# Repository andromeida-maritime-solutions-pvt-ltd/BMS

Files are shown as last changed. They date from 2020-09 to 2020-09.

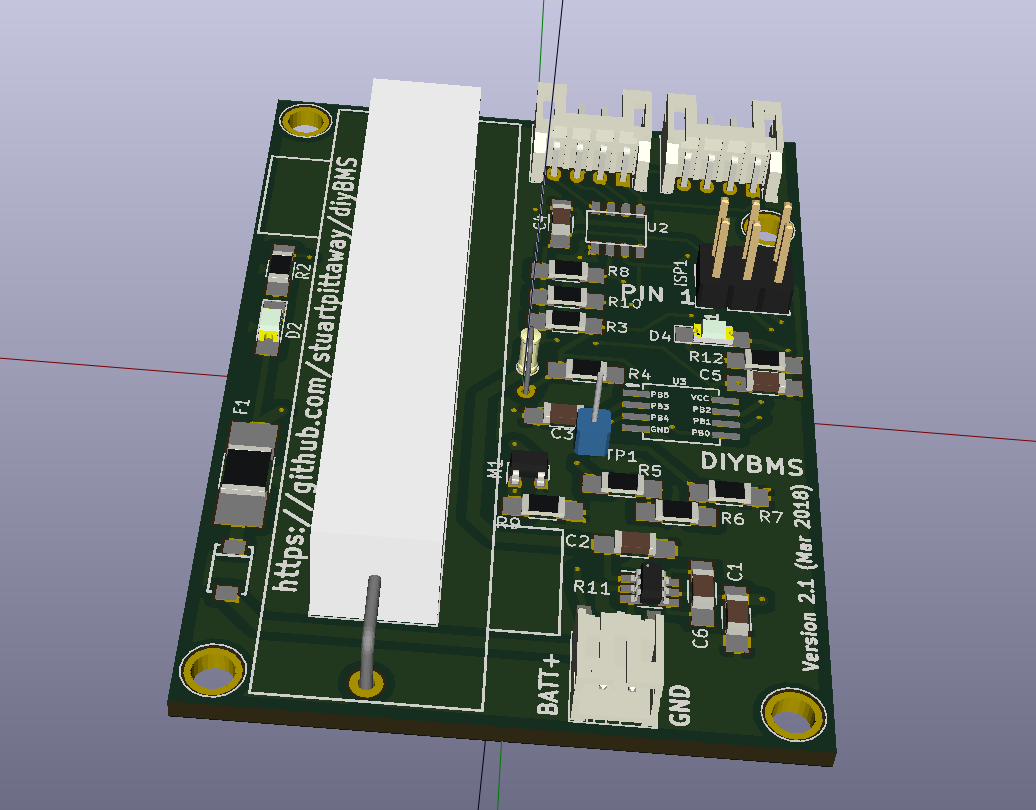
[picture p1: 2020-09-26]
BMS-Cell-Module-Circuit/BMS_Cell_Module2.png

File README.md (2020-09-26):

# diyBMS
Do it yourself battery management system to Lithium ion battery packs/cells

More discussion
https://community.openenergymonitor.org/t/diy-lithium-battery-balancer-and-monitoring-bms/5594/10

Some Youtube videos on the BMS building and testing can be found at
https://www.youtube.com/playlist?list=PLiYbY8lzAN-2qB9rR0Sc7Z7sUrsgYzsiV

# Problem

A DIY Powerwall is the DIY construction of a pack of battery cells to create an energy store which can be used via inverters to power electrical items in the home. Generally cells are salvaged/second hand, and typically use Lithium 18650 cells.

Lithium batteries need to be kept at the same voltage level across a parallel pack. This is done by balancing each cell in the pack to raise or lower its voltage to match the others.

Existing balancing solutions are available in the market place, but at a relatively high cost compared to the cost of the battery bank, so this project is to design a low-cost, simple featured BMS/balancer.

A large number of people have utilised the commercial BATRIUM BMS system in their powerwall devices.

# Parameters
**Current Situation:**
Assumption that second hand 18650 cells are made into “packs” containing tens or hundreds of cells in parallel.
Voltage of 18650 cell between 3.0V (empty) and 4.2V (full)
48V DC battery pack - running 14 packs/cells in series (aka 14S) this gives between 42V and 58.8V DC
Battery expected to output (1000W) so produce up to 25A current (depending on battery voltage)
Charger and inverter would be commercial products (not DIY) to comply with necessary approvals
BMS Design
Building upon my existing skill set and knowledge, and also building something that others can contribute to using regular standard libraries and off the shelf components.

* Design a hub and spoke arrangement, for a central controller and individual cell monitoring nodes on each pack (so 14 in my case)
* Use Arduino based libraries and tools (possible move to platform.io) **
* Use esp8266-12e as the controller - to take advantage of built in WIFI for monitoring/alerting and CPU/RAM performance
* Use AVR ATTINY85 for each node
* Ensure each cell voltage is isolated from other cells and that ground voltage is isolated
* Isolated communications between controller and node is needed
* Put everything on GITHUB
* Document it!

# Bill Of Materials

Typical bill of materials for each cell module, costs and part numbers provided from Farnell (UK) so other suppliers may be able to provide better costs or similar products.  The ADUM1250 unit is particularly expensive from Farnell and can be purchased for less than 1 USD if you shop around.  Excluding the ADUM1250 chip the component cost is around £5.50 GBP.

|	Quantity	|	Board Marking	|	Farnel (cost per single unit)	|	Make Model	|	Farnell URL	|
|	---	|	---	|	---	|	---	|	---	|
|	1	|	ATTINY85V-10SU SOIC-8	|	0.887	|	ATTINY85V-10SU	|	http://uk.farnell.com/atmel/attiny85v-10su/mcu-8bit-attiny-10mhz-soic-8/dp/1455166	|
|	1	|	REG710NA-3.3	|	1.20	|	REG710NA-3.3/250	|	http://uk.farnell.com/texas-instruments/reg710na-3-3-250/charge-pump-regulator-buck-boost/dp/1535743	|
|	1	|	ADUM1250ARZ SOIC-8	|	4.51	|	Analog Devices ADUM1250ARZ	|	http://uk.farnell.com/analog-devices/adum1250arz-rl7/digital-isolator-4-ch-1mbps-nsoic/dp/2758723	|
|	1	|	M1 SI2312BDS-T1-E3 MOSFET Transistor, N Channel, 3.9 A, 20 V, 0.025 ohm, 4.5 V, 850 mV	|	0.241	|	VISHAY SI2312BDS-T1-E3	|	http://uk.farnell.com/vishay/si2312bds-t1-e3/mosfet-n-ch-20v-3-9a-sot-23-3/dp/2396085	|
|	1	|	D1 SE30AFG-M3/6A Standard Recovery Diode, 400 V, 3 A, Single, 1.1 V, 1.5 µs, 40 A	|	0.306	|	VISHAY SE30AFG-M3/6A	|	http://uk.farnell.com/vishay/se30afg-m3-6a/rectifier-esd-400v-3a-do-221ac/dp/2313878	|
|	1	|	F1 MC36228 PPTC Resettable Fuse, 1.5A 8V	|	0.08	|	MultiComp MC36228	|	http://uk.farnell.com/multicomp/mc36228/fuse-ptc-reset-smd-8v-1-5a/dp/1861169	|
|	1	|	B57891M0103K000 Thermistor, NTC, 10 kohm, B57891M Series, 3950 K, Through Hole	|	0.571	|	EPCOS B57891M0103K000	|	http://uk.farnell.com/epcos/b57891m0103k000/thermistor-ntc-radial-leaded/dp/2285471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	|
|	1	|	1x GREEN LED 1206 SMT	|		|		|		|
|	1	|	1x BLUE LED 1206 SMT	|	0.12	|	King Bright KPL-3015QBC-D	|	http://uk.farnell.com/kingbright/kpl-3015qbc-d/led-blue-200mcd-465nm-smd/dp/2426226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	|
|	3	|	C3/C4/C5 0.1uF Cap 1210 SMT SMD Multilayer Ceramic Capacitor, 1210 [3225 Metric], 0.1 µF, 100 V, ± 10%, X7R, Y Series FF-CAP	|	0.15	|	KEMET C1210Y104K1RACTU	|	http://uk.farnell.com/kemet/c1210y104k1ractu/capacitor-1210-100nf-100v-x7r/dp/1520317	|
|	2	|	C1 2.2uF Cap 1210 SMT	|		|	X7R	|		|
|	2	|	C2 2.2uF Cap 1210 SMT	|		|	X7R	|		|
|	2	|	C6 0.22uF Cap 1210 SMT	|		|	X7R	|		|
|	1	|	R4 10K Resistor 1206 SMT	|		|		|		|
|	1	|	R5 47K Resistor 1206 SMT	|		|		|		|
|	1	|	R6 470K Resistor 1206 SMT	|		|		|		|
|	1	|	R7 680K Resistor 1206 SMT	|		|		|		|
|	1	|	R8 2K2 Resistor 1206 SMT	|		|		|		|
|	1	|	R3 20K Resistor 1206 SMT	|		|		|		|
|	1	|	R10 2K2 Resistor 1206 SMT	|		|		|		|
|	1	|	R11 510R Resistor 1206 SMT	|		|		|		|
|	1	|	R12 510R Resistor 1206 SMT	|		|		|		|
|	1	|	R11 2K2 Resistor 1206 SMT	|		|		|		|
|	1	|	R9 47K Resistor 1206 SMT	|		|		|		|
|	1	|	47R Resistor 1206 SMT	|		|		|		|
|	2	|	J2/J2 JST_PH_S4B-PH-K_04x2.00mm_Angled	|	0.10	|		S4B-PH-K-S (LF)(SN)	|	http://uk.farnell.com/jst-japan-solderless-terminals/s4b-ph-k-s-lf-sn/header-tht-right-angle-2mm-4way/dp/9492488	|
|	1	|	J1 	S2B-PH-K-S (LF)(SN)  	| 0.07		|	JST 	S2B-PH-K-S (LF)(SN)	|		|

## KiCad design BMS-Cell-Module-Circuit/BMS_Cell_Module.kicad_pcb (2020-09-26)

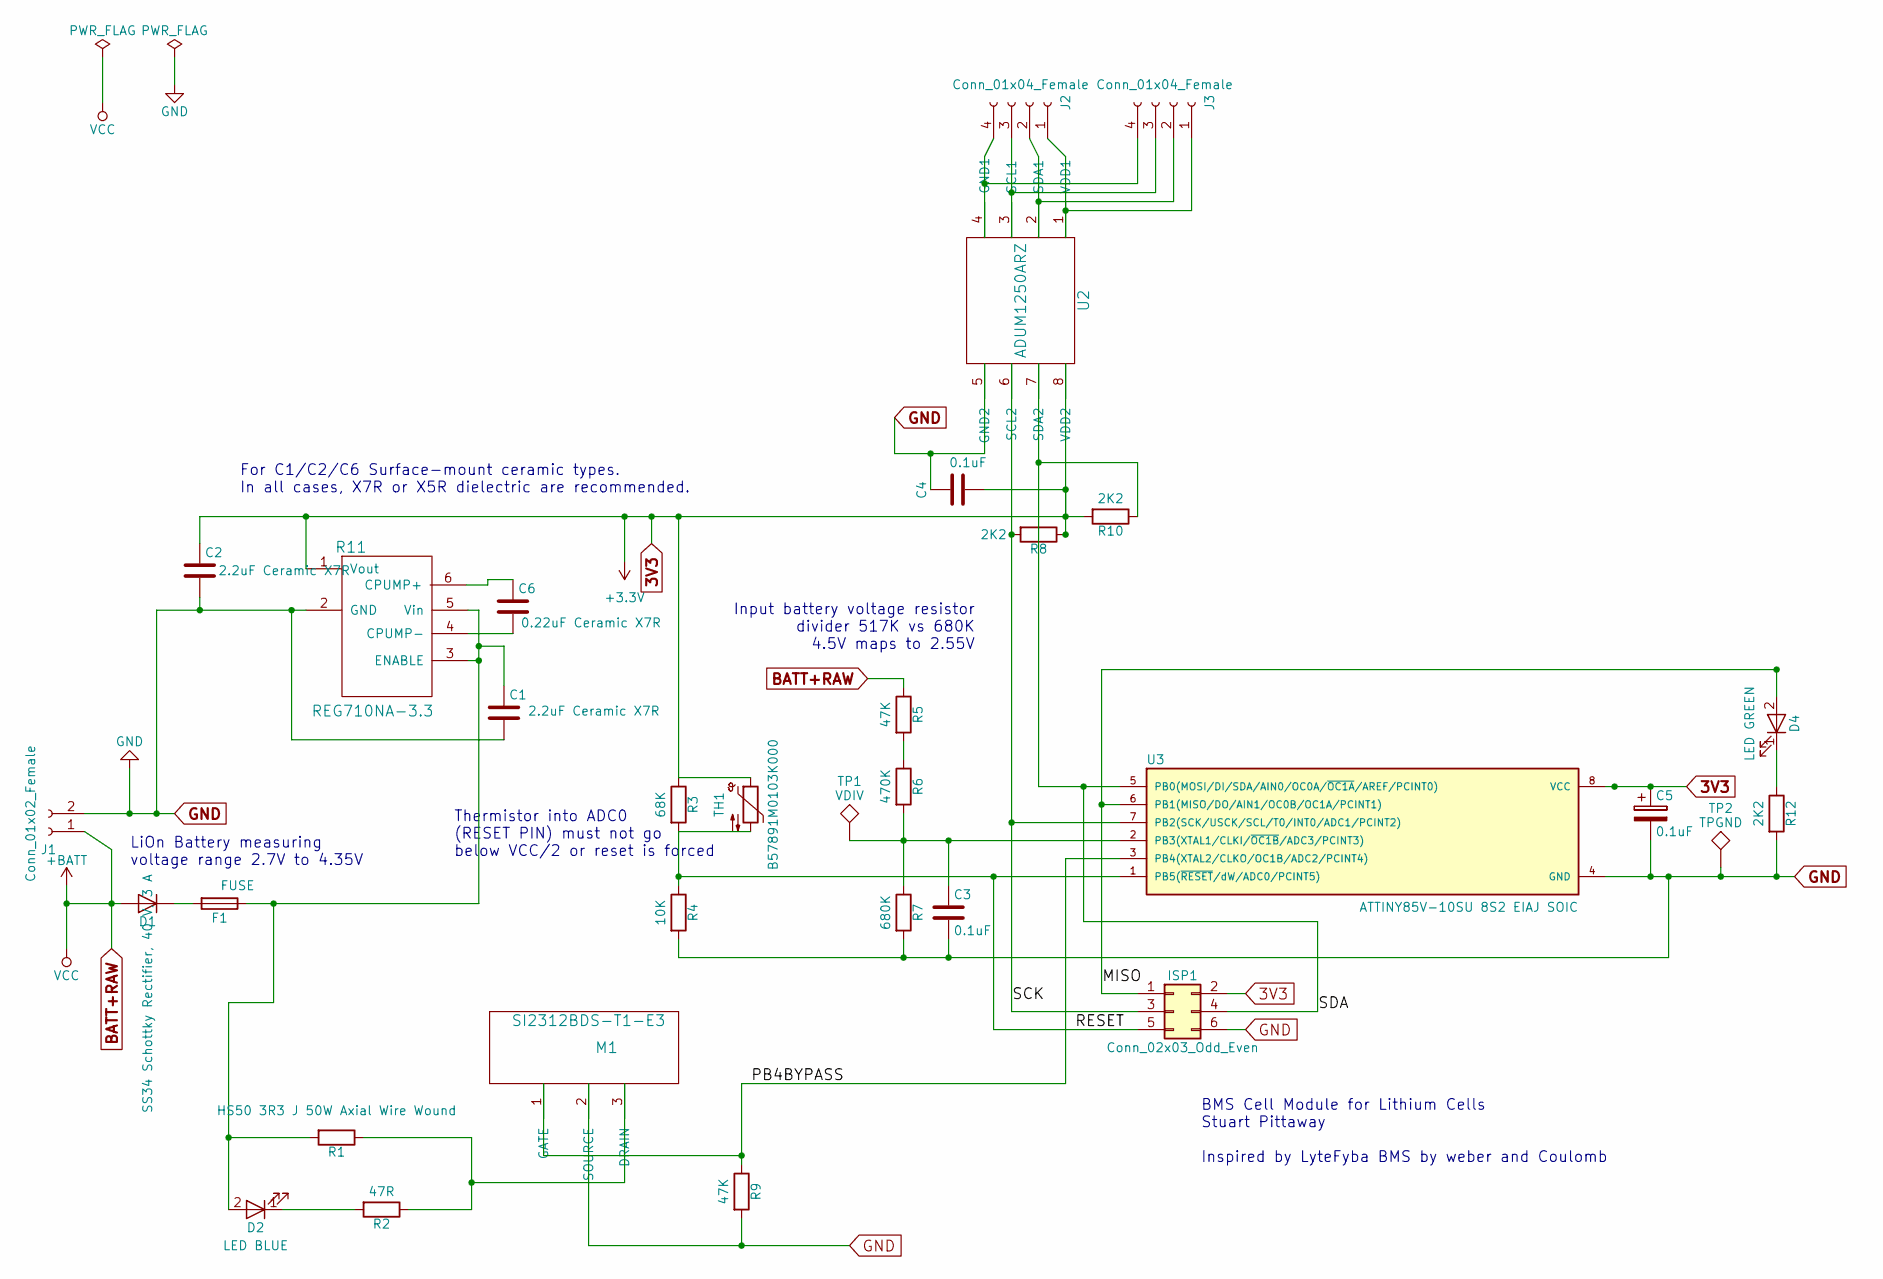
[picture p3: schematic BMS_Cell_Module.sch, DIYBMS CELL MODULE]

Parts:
C1, C2: 2.2uF Ceramic X7R; C_1206_HandSoldering
C3, C4, C5: 0.1uF; C_1206_HandSoldering
C6: 0.22uF Ceramic X7R; C_1206_HandSoldering
D1: SS34 Schottky Rectifier, 40 V, 3 A; DO-221AC
D2: LED BLUE; LED_1206_HandSoldering
D4: LED GREEN; LED_1206_HandSoldering
F1: FUSE; R_1812_HandSoldering
ISP1: Conn_02x03_Odd_Even; Pin_Header_Straight_2x03_Pitch2.54mm
J1: Conn_01x02_Female; JST_PH_S2B-PH-K_02x2.00mm_Angled
J2, J3: Conn_01x04_Female; JST_PH_S4B-PH-K_04x2.00mm_Angled
M1: SI2312BDS-T1-E3; SOT-23
R1: HS50 3R3 J 50W Axial Wire Wound; R_Axial_Power_L50.0mm_W9.0mm_P60.96mm
R2: 47R; R_1206_HandSoldering
R3: 68K; R_1206_HandSoldering
R4: 10K; R_1206_HandSoldering
R5, R9: 47K; R_1206_HandSoldering
R6: 470K; R_1206_HandSoldering
R7: 680K; R_1206_HandSoldering
R8, R10, R12: 2K2; R_1206_HandSoldering
R11: REG710NA-3.3; SOT-23-6_Handsoldering
TH1: B57891M0103K000; R_Axial_DIN0204_L3.6mm_D1.6mm_P2.54mm_Vertical
TP1: VDIV; PINTST
TP2: TPGND; PINTST
U2: ADUM1250ARZ; ADUM1250
U3: ATTINY85V-10SU 8S2 EIAJ SOIC; ATTINY85V

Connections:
3V3: C2.1, C4.1, C5.1, ISP1.2, R3.1, R8.1, R10.2, R11.1 (Vout), TH1.1, U2.8 (VDD2), U3.8 (VCC)
/MISO: D4.2 (A), ISP1.1, U3.6 (PB1(MISO/DO/AIN1/OC0B/OC1A/PCINT1))
/PB4BYPASS: M1.1 (GATE), R9.1, U3.3 (PB4(XTAL2/CLKO/OC1B/ADC2/PCINT4))
/RESET: ISP1.5, R3.2, R4.1, TH1.2, U3.1 (PB5(~RESET~/dW/ADC0/PCINT5))
/SCK: ISP1.3, R8.2, U2.6 (SCL2), U3.7 (PB2(SCK/USCK/SCL/T0/INT0/ADC1/PCINT2))
/SDA: ISP1.4, R10.1, U2.7 (SDA2), U3.5 (PB0(MOSI/DI/SDA/AIN0/OC0A/~OC1A~/AREF/P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)
BATT+RAW: D1.2 (A), J1.1, R5.1
GND: C1.2, C2.2, C3.2, C4.2, C5.2, ISP1.6, J1.2, M1.2 (SOURCE), R4.2, R7.2, R9.2, R11.2 (GND), R12.2, TP2.1, U2.5 (GND2), U3.4 (GND)
unnamed: C1.1, D2.2 (A), F1.1, R1.2, R11.3 (ENABLE), R11.5 (Vin)
unnamed: C3.1, R6.2, R7.1, TP1.1, U3.2 (PB3(XTAL1/CLKI/~OC1B~/ADC3/PCINT3))
unnamed: C6.1, R11.6 (CPUMP+)
unnamed: C6.2, R11.4 (CPUMP-)
unnamed: D1.1 (K), F1.2
unnamed: D2.1 (K), R2.2
unnamed: D4.1 (K), R12.1
unnamed: J2.1, J3.1, U2.1 (VDD1)
unnamed: J2.2, J3.2, U2.2 (SDA1)
unnamed: J2.3, J3.3, U2.3 (SCL1)
unnamed: J2.4, J3.4, U2.4 (GND1)
unnamed: M1.3 (DRAIN), R1.1, R2.1
unnamed: R5.2, R6.1

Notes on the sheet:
Input battery voltage resistor divider 517K vs 680K 4.5V maps to 2.55V
LiOn Battery measuring voltage range 2.7V to 4.35V
Thermistor into ADC0 (RESET PIN) must not go below VCC/2 or reset is forced
BMS Cell Module for Lithium Cells Stuart Pittaway Inspired by LyteFyba BMS by weber and Coulomb
For C1/C2/C6 Surface-mount ceramic types. In all cases, X7R or X5R dielectric are recommended.

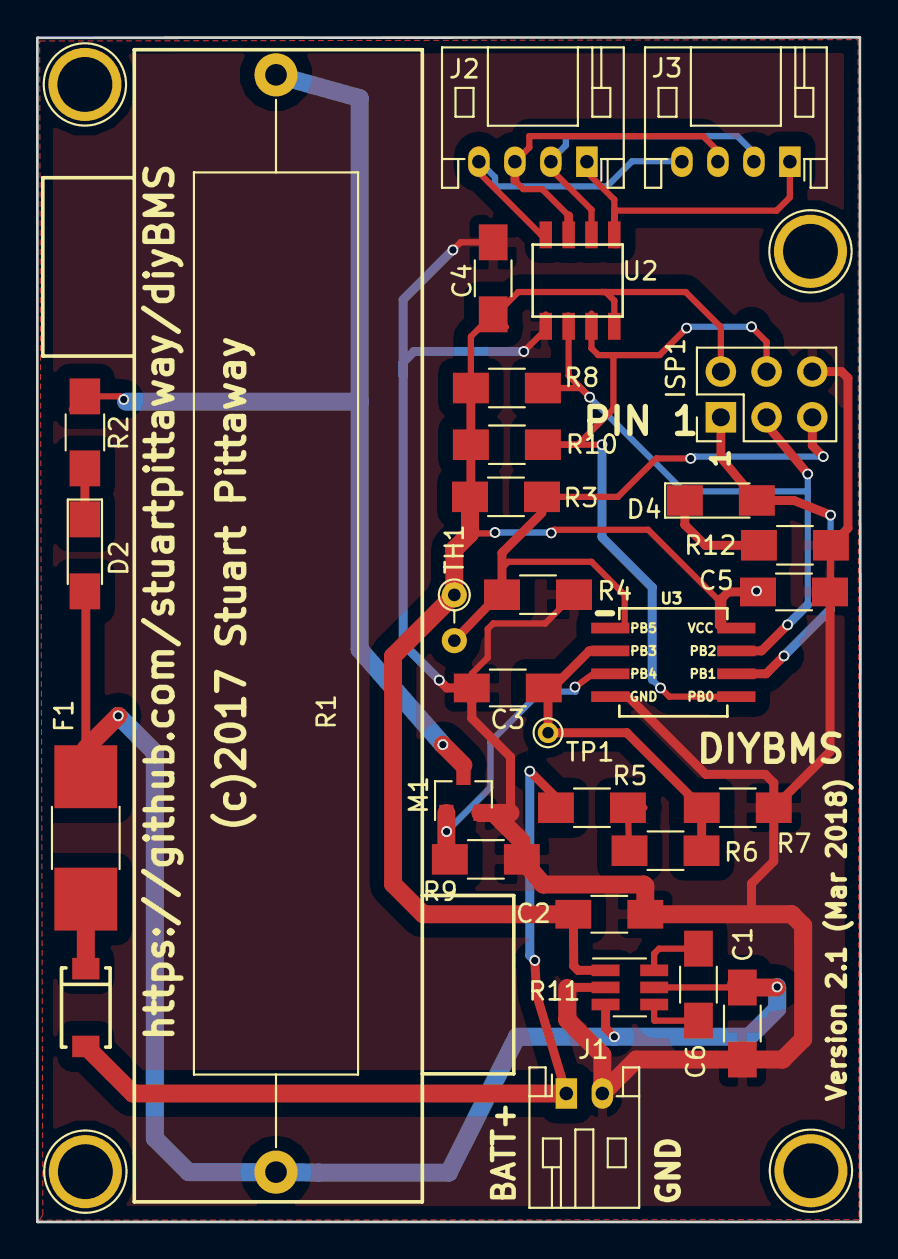
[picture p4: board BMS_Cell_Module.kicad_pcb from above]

Board: 2 copper layers, 45.7 x 65.8 mm, 31 parts (0 on the bottom side), 21 nets.

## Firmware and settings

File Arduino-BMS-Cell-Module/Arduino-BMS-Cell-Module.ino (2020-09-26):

/*
   ____  ____  _  _  ____  __  __  ___
  (  _ \(_  _)( \/ )(  _ \(  \/  )/ __)
   )(_) )_)(_  \  /  ) _ < )    ( \__ \
  (____/(____) (__) (____/(_/\/\_)(___/

  (c) 2017 Stuart Pittaway

  This is the code for the cell module (one is needed for each series cell in a modular battery array (pack))

  This code runs on ATTINY85 processors and compiles with Arduino 1.8.5 environment

  You will need a seperate programmer to program the ATTINY chips - another Arduino can be used

  Settings ATTINY85, 8MHZ INTERNAL CLOCK, LTO enabled, BOD disabled, Timer1=CPU


  Use this board manager for ATTINY85
  http://drazzy.com/package_drazzy.com_index.json
  not this one https://raw.githubusercontent.com/damellis/attiny/ide-1.6.x-boards-manager/package_damellis_attiny_index.json

  ATTINY85/V-10PU data sheet
  http://www.atmel.com/images/atmel-2586-avr-8-bit-microcontroller-attiny25-attiny45-attiny85_datasheet.pdf

  To manually configure ATTINY fuses use the command....
  .\bin\avrdude -p attiny85 -C etc\avrdude.conf -c avrisp -P COM5 -b 19200 -B2 -e -Uefuse:w:0xff:m -Uhfuse:w:0xdf:m -Ulfuse:w:0xe2:m
  If you burn incorrect fuses to ATTINY85 you may need to connect a crystal over the pins to make it work again!
*/


//Show error is not targetting ATTINY85
#if !(defined(__AVR_ATtiny85__))
#error Written for ATTINY85/V chip
#endif

#if !(F_CPU == 8000000)
#error Processor speed should be 8Mhz internal
#endif

#include <USIWire.h>
#include <EEPROM.h>
#include <avr/sleep.h>
#include <avr/wdt.h>

// __DATE__

//LED light patterns
#define GREEN_LED_PATTERN_STANDARD 0
#define GREEN_LED_PATTERN_BYPASS B01101100
#define GREEN_LED_PANIC B01010101
#define GREEN_LED_PATTERN_UNCONFIGURED B11101111

//Where in EEPROM do we store the configuration
#define EEPROM_CHECKSUM_ADDRESS 0
#define EEPROM_CONFIG_ADDRESS 20

#define MIN_BYPASS_VOLTAGE 3000U
#define MAX_BYPASS_VOLTAGE 4200U

//Number of TIMER1 cycles between voltage reading checks (240 = approx 30 seconds)
#define BYPASS_COUNTER_MAX 240

//Default i2c SLAVE address (used for auto provision of address)
#define DEFAULT_SLAVE_ADDR 21

//Configured cell modules use i2c addresses 24 to 48 (24S)
#define DEFAULT_SLAVE_ADDR_START_RANGE 24
#define DEFAULT_SLAVE_ADDR_END_RANGE DEFAULT_SLAVE_ADDR_START_RANGE + 24

//Number of times we sample and average the ADC for voltage
#define OVERSAMPLE_LOOP 16

//If we receive a cmdByte with BIT 6 set its a command byte so there is another byte waiting for us to process
#define COMMAND_BIT 6

#define COMMAND_green_led_pattern   1
//unused #define COMMAND_led_off   2
#define COMMAND_factory_default 3
#define COMMAND_set_slave_address 4
#define COMMAND_green_led_default 5
#define COMMAND_set_voltage_calibration 6
#define COMMAND_set_temperature_calibration 7
#define COMMAND_set_bypass_voltage 8
#define COMMAND_set_load_resistance 9


#define read_voltage 10
#define read_temperature 11
#define read_voltage_calibration 12
#define read_temperature_calibration 13
#define read_raw_voltage 14
#define read_error_counter 15
#define read_bypass_enabled_state 16
#define read_bypass_voltage_measurement 17
#define read_load_resistance 18

volatile bool skipNextADC = false;
volatile uint8_t green_pattern = GREEN_LED_PATTERN_STANDARD;
volatile uint16_t analogVal[OVERSAMPLE_LOOP];
volatile uint16_t temperature_probe = 0;
volatile uint8_t analogValIndex;
volatile uint8_t buffer_ready = 0;
volatile uint8_t reading_count = 0;
volatile uint8_t cmdByte = 0;

volatile uint8_t last_i2c_request = 255;
volatile uint16_t VCCMillivolts = 0;
volatile uint16_t ByPassVCCMillivolts = 0;
volatile uint16_t last_raw_adc = 0;
volatile uint16_t targetByPassVoltage = 0;
volatile uint8_t ByPassCounter = 0;
volatile boolean ByPassEnabled = false;
volatile boolean flash_green = false;

uint16_t error_counter = 0;

bool flashLed;

//Number of voltage readings to take before we take a temperature reading
#define TEMP_READING_LOOP_FREQ 16

//Default values
struct cell_module_config {
  // 7 bit slave I2C address
  uint8_t SLAVE_ADDR = DEFAULT_SLAVE_ADDR;
  // Calibration factor for voltage readings
  float VCCCalibration = 4.430;
  // Calibration factor for temp readings
  float TemperatureCalibration = 1.080;
  // Resistance of bypass load
  float LoadResistance = 10.0;
};

static cell_module_config myConfig;

void setup() {
  //Must be first line of setup()
  MCUSR &= ~(1 << WDRF); // reset status flag
  wdt_disable();

  //Pins PB0 (SDA) and PB2 (SCLOCK) are for the i2c comms with master
  //PINS https://github.com/SpenceKonde/ATTinyCore/blob/master/avr/extras/ATtiny_x5.md

  //pinMode(A3, INPUT);  //A3 pin 3 (PB3)
  //pinMode(A0, INPUT);  //reset pin A0 pin 5 (PB5)

  /*
    DDRB &= ~(1 << DDB3);
    PORTB &= ~(1 << PB3);

    DDRB &= ~(1 << DDB5);
    PORTB &= ~(1 << PB5);
  */

  pinMode(PB4, OUTPUT); //PB4 = PIN 3
  digitalWrite(PB4, LOW);

  ledGreen();
  delay(500);
  ledOff();

  //Load our EEPROM configuration
  if (!LoadConfigFromEEPROM()) {
    //Do something here for bad configuration??
  }

  cli();//stop interrupts

  analogValIndex = 0;

  initTimer1();
  initADC();

  // WDTCSR configuration:     WDIE = 1: Interrupt Enable     WDE = 1 :Reset Enable
  // Enter Watchdog Configuration mode:
  WDTCR |= (1 << WDCE) | (1 << WDE);

  // Set Watchdog settings - 4000ms timeout
  WDTCR = (1 << WDIE) | (1 << WDE) | (1 << WDP3) | (0 << WDP2) | (0 << WDP1) | (0 << WDP0);

  // Enable Global Interrupts
  sei();

  LEDReset();
  wait_for_buffer_ready();
  LEDReset();

  init_i2c();
}

boolean inPanicMode = false;

void panic() {
  green_pattern = GREEN_LED_PANIC;
  inPanicMode = true;
}

uint8_t previousLedState = 0;
void loop() {
  wdt_reset();

  if (last_i2c_request > 0) {
    //Count down loop for requests to see if i2c bus hangs or controller stops talking
    last_i2c_request--;
  }

  //If we are on the default SLAVE address then use different LED pattern to indicate this
  if (myConfig.SLAVE_ADDR == DEFAULT_SLAVE_ADDR) {
    green_pattern = GREEN_LED_PATTERN_UNCONFIGURED;
  } else {
    //We have had at least one i2c request and not currently in PANIC mode
    if (last_i2c_request == 0 && inPanicMode == false) {

      previousLedState = green_pattern ;

      //Panic after a few seconds of not receiving i2c requests...
      panic();

      //Try resetting the i2c bus
      Wire.end();
      init_i2c();

      error_counter++;
    }

    if (last_i2c_request > 0 && inPanicMode == true) {
      //Just come back from a PANIC situation
      LEDReset();
      green_pattern = previousLedState;
      inPanicMode = false;
    }

  }

  //Dont make this very large or watchdog will reset
  delay(250);
}

uint32_t calculateCRC32(const uint8_t *data, size_t length)
{
  uint32_t crc = 0xffffffff;
  while (length--) {
    uint8_t c = *data++;
    for (uint32_t i = 0x80; i > 0; i >>= 1) {
      bool bit = crc & 0x80000000;
      if (c & i) {
        bit = !bit;
      }
      crc <<= 1;
      if (bit) {
        crc ^= 0x04c11db7;
      }
    }
  }
  return crc;
}

void WriteConfigToEEPROM() {
  EEPROM.put(EEPROM_CONFIG_ADDRESS, myConfig);
  EEPROM.put(EEPROM_CHECKSUM_ADDRESS, calculateCRC32((uint8_t*)&myConfig, sizeof(cell_module_config)));
}

bool LoadConfigFromEEPROM() {
  cell_module_config restoredConfig;
  uint32_t existingChecksum;

  EEPROM.get(EEPROM_CONFIG_ADDRESS, restoredConfig);
  EEPROM.get(EEPROM_CHECKSUM_ADDRESS, existingChecksum);

  // Calculate the checksum of an entire buffer at once.
  uint32_t checksum = calculateCRC32((uint8_t*)&restoredConfig, sizeof(cell_module_config));

  if (checksum == existingChecksum) {
    //Clone the config into our global variable and return all OK
    memcpy(&myConfig, &restoredConfig, sizeof(cell_module_config));
    return true;
  }

  //Config is not configured or gone bad, return FALSE
  return false;
}

void init_i2c() {
  Wire.begin(myConfig.SLAVE_ADDR);
  Wire.onRequest(requestEvent);
  Wire.onReceive(receiveEvent);
}

void LEDReset() {
  green_pattern = GREEN_LED_PATTERN_STANDARD;
}

void factory_default() {
  EEPROM.put(EEPROM_CHECKSUM_ADDRESS, 0);
}

void Reboot() {
  TCCR1 = 0;
  TIMSK |= (1 << OCIE1A); //Disable timer1

  //Now power down loop until the watchdog timer kicks a reset
  ledGreen();

  /*
    set_sleep_mode(SLEEP_MODE_PWR_DOWN);
    adc_disable();
    sleep_enable();
    sleep_cpu();
  */
  //Infinity
  while (1) {}
}

void wait_for_buffer_ready() {
  //Just delay here so the buffers are all ready before we service i2c
  while (!buffer_ready) {
    delay(100);
    wdt_reset();
  }
}


void sendUnsignedInt(uint16_t number) {
  Wire.write((byte)((number >> 8) & 0xFF));
  Wire.write((byte)(number & 0xFF));
}

void sendByte(uint8_t number) {
  Wire.write(number);
}


union {
  float val;
  uint8_t b[4];
} float_to_bytes;

void sendFloat(float number) {
  float_to_bytes.val = number;

  Wire.write(float_to_bytes.b[0]);
  Wire.write(float_to_bytes.b[1]);
  Wire.write(float_to_bytes.b[2]);
  Wire.write(float_to_bytes.b[3]);
}

float readFloat() {
  float_to_bytes.b[0] = Wire.read();
  float_to_bytes.b[1] = Wire.read();
  float_to_bytes.b[2] = Wire.read();
  float_to_bytes.b[3] = Wire.read();

  return float_to_bytes.val;
}

void bypass_off() {
  targetByPassVoltage = 0;
  ByPassCounter = 0;
  ByPassEnabled = false;
  green_pattern = GREEN_LED_PATTERN_STANDARD;
}

union {
  uint16_t val;
  uint8_t b[2];
} uint16_t_to_bytes;

uint16_t readUINT16() {
  uint16_t_to_bytes.b[0] = Wire.read();
  uint16_t_to_bytes.b[1] = Wire.read();
  return uint16_t_to_bytes.val;
}

// function that executes whenever data is received from master
void receiveEvent(int howMany) {
  if (howMany <= 0) return;

  //If cmdByte is not zero then something went wrong in the i2c comms,
  //master failed to request any data after command
  if (cmdByte != 0) error_counter++;

  flashLed = true;

  cmdByte = Wire.read();
  howMany--;

  //Is it a command byte (there are other bytes to process) or not?
  if (bitRead(cmdByte, COMMAND_BIT)) {

    bitClear(cmdByte, COMMAND_BIT);

    switch (cmdByte) {
      case COMMAND_green_led_pattern:
        if (howMany == 1) {
          green_pattern = Wire.read();
        }
        break;

      case COMMAND_green_led_default:
        green_pattern = GREEN_LED_PATTERN_STANDARD;
        break;

      case COMMAND_factory_default:
        factory_default();
        Reboot();
        break;

      case COMMAND_set_voltage_calibration:
        if (howMany == sizeof(float)) {
          float newValue = readFloat();
          //Only accept if its different
          if (newValue != myConfig.VCCCalibration) {
            myConfig.VCCCalibration = newValue;
            WriteConfigToEEPROM();
          }
        }
        break;

      case COMMAND_set_temperature_calibration:
        if (howMany == sizeof(float)) {
          float newValue = readFloat();
          //Only accept if its different
          if (newValue != myConfig.TemperatureCalibration) {
            myConfig.TemperatureCalibration = newValue;
            WriteConfigToEEPROM();
          }
        }
        break;

      case COMMAND_set_load_resistance:
        if (howMany == sizeof(float)) {
          float newValue = readFloat();
          //Only accept if its different
          if (newValue != myConfig.LoadResistance) {
            myConfig.LoadResistance = newValue;
            WriteConfigToEEPROM();
          }
        }
        break;

      case COMMAND_set_bypass_voltage:
        if (howMany == sizeof(uint16_t)) {
          uint16_t newValue = readUINT16();
          //Only accept if its a realistic value and the value is LESS than the last voltage reading
          if (newValue >= MIN_BYPASS_VOLTAGE && newValue <= MAX_BYPASS_VOLTAGE && newValue < VCCMillivolts) {
            //TODO: Are we sure we really need all these variables??
            targetByPassVoltage = newValue;
            ByPassVCCMillivolts = VCCMillivolts;
            ByPassCounter = BYPASS_COUNTER_MAX;
            green_pattern = GREEN_LED_PATTERN_BYPASS;
            ByPassEnabled = true;
          } else {
            //Disable
            bypass_off();
          }
        }
        break;


      case COMMAND_set_slave_address:
        //Set i2c slave address and write to EEPROM, then reboot
        if (howMany == 1 ) {
          uint8_t newAddress = Wire.read();
          //Only accept if its a different address
          if (newAddress != myConfig.SLAVE_ADDR && newAddress >= DEFAULT_SLAVE_ADDR_START_RANGE && newAddress <= DEFAULT_SLAVE_ADDR_END_RANGE) {
            myConfig.SLAVE_ADDR = newAddress;
            WriteConfigToEEPROM();
            Reboot();
          }
        }
        break;

    }

    cmdByte = 0;
  } else {
    //Its a READ request

    switch (cmdByte) {
      case read_voltage:
        VCCMillivolts = Update_VCCMillivolts();
        flash_green = true;
        break;
    }
  }

  // clear rx buffer
  while (Wire.available()) Wire.read();
}


float Update_VCCMillivolts() {
  //Oversampling and take average of ADC samples use an unsigned integer or the bit shifting goes wonky
  uint32_t extraBits = 0;
  for (int k = 0; k < OVERSAMPLE_LOOP; k++) {
    extraBits = extraBits + analogVal[k];
  }
  //Shift the bits to match OVERSAMPLE_LOOP size (buffer size of 8=3 shifts, 16=4 shifts)
  //Assume perfect reference of 2560mV for reference - we will correct for this with VCCCalibration

  uint16_t raw = (extraBits >> 4);
  //TODO: DONT THINK WE NEED THIS ANY LONGER!
  //unsigned int raw = map((extraBits >> 4), 0, 1023, 0, 2560);

  //TODO: Get rid of the need for float variables....
  return (int)((float)raw * myConfig.VCCCalibration);
}

// function that executes whenever data is requested by master (this answers requestFrom command)
void requestEvent() {
  switch (cmdByte) {
    case read_voltage:
      //If we are in bypass then only return the voltage
      //thats taken outside of the resistor load being switched on
      if (ByPassEnabled) {
        sendUnsignedInt(ByPassVCCMillivolts);
      } else {
        sendUnsignedInt(VCCMillivolts);
      }

      break;

    case read_raw_voltage:
      sendUnsignedInt(last_raw_adc);
      break;

    case read_error_counter:
      sendUnsignedInt(error_counter);
      break;

    case read_bypass_voltage_measurement:
      sendUnsignedInt(ByPassVCCMillivolts);
      break;

    case read_bypass_enabled_state:
      sendByte(ByPassEnabled);
      break;

    case read_temperature:
      sendUnsignedInt((uint16_t)((float)temperature_probe * myConfig.TemperatureCalibration));
      break;

    case read_voltage_calibration:
      sendFloat(myConfig.VCCCalibration);
      break;

    case read_temperature_calibration:
      sendFloat(myConfig.TemperatureCalibration);
      break;

    case read_load_resistance:
      sendFloat(myConfig.LoadResistance);
      break;

    default:
      //Dont do anything - timeout
      break;
  }

  //Clear cmdByte
  cmdByte = 0;

  //Reset when we last processed a request, if this times out master has stopped communicating with module
  last_i2c_request = 150;
}

inline void ledGreen() {
  DDRB |= (1 << DDB1);
  PORTB |=  (1 << PB1);
}

/*
  inline void ledRed() {
  DDRB |= (1 << DDB1);
  PORTB &= ~(1 << PB1);
  }
*/
inline void ledOff() {
  //Low
  DDRB |= (1 << DDB1);
  PORTB &= ~(1 << PB1);
  /*
    //PB1 as input
    DDRB &= ~(1 << DDB1);
    //PB1 pull up OFF
    PORTB &= ~(1 << PB1);
  */
}

ISR(TIMER1_COMPA_vect)
{
  //Flash LED in sync with bit pattern


  if (green_pattern == 0) {
    if (flash_green)  {
      ledGreen();
    }
    flash_green = false;
  } else {
    ///Rotate pattern
    green_pattern = (byte)(green_pattern << 1) | (green_pattern >> 7);

    if (green_pattern & 0x01) {
      ledGreen();
    } else {
      ledOff();
    }
  }

  if (ByPassEnabled) {

    //TODO: We need to add in code here to check we don't overheat

    //This must go above the following "if (ByPassCounter > 0)" statement...
    if (ByPassCounter == 0 && analogValIndex == 0) {
      //We are in bypass and just finished an in-cycle voltage measurement
      ByPassVCCMillivolts = Update_VCCMillivolts();

      if (targetByPassVoltage >= ByPassVCCMillivolts) {
        //We reached the goal
        bypass_off();
      } else {
        //Try again
        ByPassCounter = BYPASS_COUNTER_MAX;
      }
    }

    if (ByPassCounter > 0)
    {
      //We are in ACTIVE BYPASS mode - the RESISTOR will be ACTIVE + BURNING ENERGY
      ByPassCounter--;
      digitalWrite(PB4, HIGH);

      if (ByPassCounter == 0)
      {
        //We have just finished this timed ACTIVE BYPASS mode, disable resistor
        //and measure resting voltage now before possible re-enable.
        digitalWrite(PB4, LOW);

        //Reset voltage ADC buffer
        analogValIndex = 0;
      }
    }

  } else {
    //Safety check we ensure bypass is always off if not enabled
    digitalWrite(PB4, LOW);
  }

  if (green_pattern == 0) {
    ledOff();
  }


  //trigger ADC reading
  ADCSRA |= (1 << ADSC);
}

ISR(ADC_vect) {
  // Interrupt service routine for the ADC completion
  //uint8_t adcl = ADCL;
  //uint16_t value = ADCH << 8 | adcl;

  uint16_t value = ADCW;

  //If we skip this ADC reading, quit ISR here
  if (skipNextADC) {
    skipNextADC = false;
    return;
  }

  if (reading_count == TEMP_READING_LOOP_FREQ ) {
    //Use A0 (RESET PIN) to act as an analogue input
    //note that we cannot take the pin below 1.4V or the CPU resets
    //so we use the top half between 1.6V and 2.56V (voltage reference)
    //we avoid switching references (VCC vs 2.56V) so the capacitors dont have to keep draining and recharging
    reading_count = 0;

    //We reduce the value by 512 as we have a DC offset we need to remove
    temperature_probe = value;

    // use ADC3 for input for next reading (voltage)
    ADMUX = B10010011;

    //Set skipNextADC to delay the next TIMER1 call to ADC reading to allow the ADC to settle after changing MUX
    skipNextADC = true;

  } else {

    //Populate the rolling buffer with values from the ADC
    last_raw_adc = value;
    analogVal[analogValIndex] = value;

    analogValIndex++;

    if (analogValIndex == OVERSAMPLE_LOOP) {
      analogValIndex = 0;
      buffer_ready = 1;
    }

    reading_count++;

    if (reading_count == TEMP_READING_LOOP_FREQ) {
      //use ADC0 for temp probe input on next ADC loop

      //We have to set the registers directly because the ATTINYCORE appears broken for internal 2v56 register without bypass capacitor
      ADMUX = B10010000;

      //Set skipNextADC to delay the next TIMER1 call to ADC reading to allow the ADC to settle after changing MUX
      skipNextADC = true;
    }
  }

}

void initADC()
{
  /* this function initialises the ADC

        ADC Prescaler Notes:
    --------------------

     ADC Prescaler needs to be set so that the ADC input frequency is between 50 - 200kHz.

           For more information, see table 17.5 "ADC Prescaler Selections" in
           chapter 17.13.2 "ADCSRA – ADC Control and Status Register A"
          (pages 140 and 141 on the complete ATtiny25/45/85 datasheet, Rev. 2586M–AVR–07/10)

           Valid prescaler values for various clock speeds

       Clock   Available prescaler values
           ---------------------------------------
             1 MHz   8 (125kHz), 16 (62.5kHz)
             4 MHz   32 (125kHz), 64 (62.5kHz)
             8 MHz   64 (125kHz), 128 (62.5kHz)
            16 MHz   128 (125kHz)


    ADPS2 ADPS1 ADPS0 Division Factor
    000 2
    001 2
    010 4
    011 8
    100 16
    101 32
    110 64
    111 128

  */

  //NOTE The device requries a supply voltage of 3V+ in order to generate 2.56V reference voltage.
  // http://openenergymonitor.blogspot.co.uk/2012/08/low-level-adc-control-admux.html

  //REFS1 REFS0 ADLAR REFS2 MUX3 MUX2 MUX1 MUX0
  //Internal 2.56V Voltage Reference without external bypass capacitor, disconnected from PB0 (AREF)
  //ADLAR =0 and PB3 (B0011) for INPUT (A3)
  //We have to set the registers directly because the ATTINYCORE appears broken for internal 2v56 register without bypass capacitor
  ADMUX = B10010011;

  /*
    ADMUX = (INTERNAL2V56_NO_CAP << 4) |
          (0 << ADLAR)  |     // dont left shift ADLAR
          (0 << MUX3)  |     // use ADC3 for input (PB4), MUX bit 3
          (0 << MUX2)  |     // use ADC3 for input (PB4), MUX bit 2
          (1 << MUX1)  |     // use ADC3 for input (PB4), MUX bit 1
          (1 << MUX0);       // use ADC3 for input (PB4), MUX bit 0
  */

  /*
    #if (F_CPU == 1000000)
    //Assume 1MHZ clock so prescaler to 8 (B011)
    ADCSRA =
      (1 << ADEN)  |     // Enable ADC
      (0 << ADPS2) |     // set prescaler bit 2
      (1 << ADPS1) |     // set prescaler bit 1
      (1 << ADPS0);      // set prescaler bit 0
    #endif
  */
  //#if (F_CPU == 8000000)
  //8MHZ clock so set prescaler to 64 (B110)
  ADCSRA =
    (1 << ADEN)  |     // Enable ADC
    (1 << ADPS2) |     // set prescaler bit 2
    (1 << ADPS1) |     // set prescaler bit 1
    (0 << ADPS0) |       // set prescaler bit 0
    (1 << ADIE);     //enable the ADC interrupt.
  //#endif
}

static inline void initTimer1(void)
{
  TCCR1 |= (1 << CTC1);  // clear timer on compare match
  TCCR1 |= (1 << CS13) | (1 << CS12) | (1 << CS11) | (1 << CS10); //clock prescaler 16384
  OCR1C = 64;  //About eighth of a second trigger Timer1  (there are 488 counts per second @ 8mhz)
  TIMSK |= (1 << OCIE1A); // enable compare match interrupt
}
